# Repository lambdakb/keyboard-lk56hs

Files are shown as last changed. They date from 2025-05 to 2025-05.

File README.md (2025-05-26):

# LK56HS 55% Staggered Hot-Swappable Keyboard






## Layout

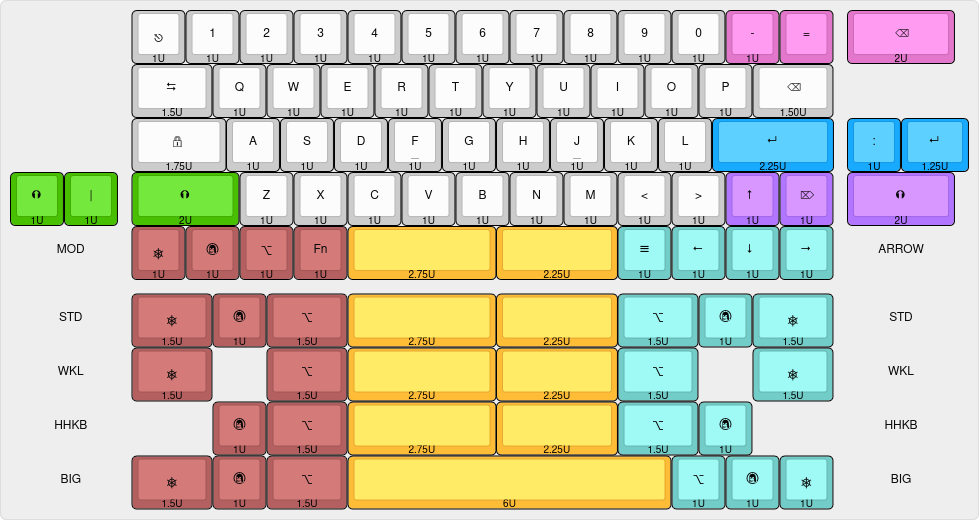
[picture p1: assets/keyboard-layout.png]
Layout


[Keyboard Layout Editor](https://www.keyboard-layout-editor.com/##@_css=%3B&@_x:2.25&p=R1&a:7%3B&=%3Ci%20class%2F='mss%20mss-Unicode-Escape-3'%3E%3C%2F%2Fi%3E%0A%0A%0A%0A1U&=1%0A%0A%0A%0A1U&=2%0A%0A%0A%0A1U&=3%0A%0A%0A%0A1U&=4%0A%0A%0A%0A1U&=5%0A%0A%0A%0A1U&=6%0A%0A%0A%0A1U&=7%0A%0A%0A%0A1U&=8%0A%0A%0A%0A1U&=9%0A%0A%0A%0A1U&=0%0A%0A%0A%0A1U&_c=%23e377cc%3B&=-%0A%0A%0A%0A1U&=%2F=&_x:0.25&p=R4&w:2%3B&=%3Ci%20class%2F='kb%20kb-Unicode-BackSpace-DeleteLeft-Big'%3E%3C%2F%2Fi%3E%0A%0A%0A%0A2U%3B&@_x:2.25&c=%23cccccc&p=R2&w:1.5%3B&=%3Ci%20class%2F='kb%20kb-Tab-1'%3E%3C%2F%2Fi%3E%0A%0A%0A%0A1.5U&=Q%0A%0A%0A%0A1U&=W%0A%0A%0A%0A1U&=E%0A%0A%0A%0A1U&=R%0A%0A%0A%0A1U&=T%0A%0A%0A%0A1U&=Y%0A%0A%0A%0A1U&=U%0A%0A%0A%0A1U&=I%0A%0A%0A%0A1U&=O%0A%0A%0A%0A1U&=P%0A%0A%0A%0A1U&_w:1.5%3B&=%3Ci%20class%2F='kb%20kb-Unicode-BackSpace-DeleteLeft-Big'%3E%3C%2F%2Fi%3E%0A%0A%0A%0A1.50U%3B&@_x:2.25&p=R3&w:1.75%3B&=%3Ci%20class%2F='kb%20kb-Unicode-Lock-Closed-1'%3E%3C%2F%2Fi%3E%0A%0A%0A%0A1.75U&=A%0A%0A%0A%0A1U&=S%0A%0A%0A%0A1U&=D%0A%0A%0A%0A1U&_n:true%3B&=F%0A%0A%0A%0A1U&=G%0A%0A%0A%0A1U&=H%0A%0A%0A%0A1U&_n:true%3B&=J%0A%0A%0A%0A1U&=K%0A%0A%0A%0A1U&=L%0A%0A%0A%0A1U&_c=%2317aaff&p=R4&w:2.25%3B&=%3Ci%20class%2F='kb%20kb-Return-2'%3E%3C%2F%2Fi%3E%0A%0A%0A%0A2.25U&_x:0.25%3B&=%2F:%0A%0A%0A%0A1U&_w:1.25%3B&=%3Ci%20class%2F='kb%20kb-Return-2'%3E%3C%2F%2Fi%3E%0A%0A%0A%0A1.25U%3B&@_c=%2348bf00%3B&=%3Ci%20class%2F='kb%20kb-Arrows-Up-Circle-Filled'%3E%3C%2F%2Fi%3E%0A%0A%0A%0A1U&=%7C%0A%0A%0A%0A1U&_x:0.25&w:2%3B&=%3Ci%20class%2F='kb%20kb-Arrows-Up-Circle-Filled'%3E%3C%2F%2Fi%3E%0A%0A%0A%0A2U&_c=%23cccccc%3B&=Z%0A%0A%0A%0A1U&=X%0A%0A%0A%0A1U&=C%0A%0A%0A%0A1U&=V%0A%0A%0A%0A1U&=B%0A%0A%0A%0A1U&=N%0A%0A%0A%0A1U&=M%0A%0A%0A%0A1U&=%3C%0A%0A%0A%0A1U&=%3E%0A%0A%0A%0A1U&_c=%23b275ff%3B&=%3Ci%20class%2F='kb%20kb-Arrows-Up'%3E%3C%2F%2Fi%3E%0A%0A%0A%0A1U&=%3Ci%20class%2F='kb%20kb-Unicode-DeleteRight-Big'%3E%3C%2F%2Fi%3E%0A%0A%0A%0A1U&_x:0.25&w:2%3B&=%3Ci%20class%2F='kb%20kb-Arrows-Up-Circle-Filled'%3E%3C%2F%2Fi%3E%0A%0A%0A%0A2U%3B&@_c=%23cccccc&p=R2&w:2.25&d:true%3B&=MOD&_c=%23b56060&p=R4%3B&=%3Ci%20class%2F='mss%20mss-Unicode-Control-4'%3E%3C%2F%2Fi%3E%0A%0A%0A%0A1U&=%3Ci%20class%2F='kb%20kb-logo-linux-tux-ibm'%3E%3C%2F%2Fi%3E%0A%0A%0A%0A1U&=%3Ci%20class%2F='mss%20mss-Unicode-Option-3'%3E%3C%2F%2Fi%3E%0A%0A%0A%0A1U&=Fn%0A%0A%0A%0A1U&_c=%23ffbc36&p=SPACE&w:2.75%3B&=%0A%0A%0A%0A2.75U&_w:2.25%3B&=%0A%0A%0A%0A2.25U&_c=%2372ccc7%3B&=%3Ci%20class%2F='kb%20kb-Hamburger-Menu'%3E%3C%2F%2Fi%3E%0A%0A%0A%0A1U&_p=R2%3B&=%3Ci%20class%2F='kb%20kb-Arrows-Left'%3E%3C%2F%2Fi%3E%0A%0A%0A%0A1U&=%3Ci%20class%2F='kb%20kb-Arrows-Down'%3E%3C%2F%2Fi%3E%0A%0A%0A%0A1U&=%3Ci%20class%2F='kb%20kb-Arrows-Right'%3E%3C%2F%2Fi%3E%0A%0A%0A%0A1U&_c=%23cccccc&w:2.5&d:true%3B&=ARROW%3B&@_y:0.25&w:2.25&d:true%3B&=STD&_c=%23b56060&p=R4&w:1.5%3B&=%3Ci%20class%2F='mss%20mss-Unicode-Control-4'%3E%3C%2F%2Fi%3E%0A%0A%0A%0A1.5U&=%3Ci%20class%2F='kb%20kb-logo-linux-tux-ibm'%3E%3C%2F%2Fi%3E%0A%0A%0A%0A1U&_w:1.5%3B&=%3Ci%20class%2F='mss%20mss-Unicode-Option-3'%3E%3C%2F%2Fi%3E%0A%0A%0A%0A1.5U&_c=%23ffbc36&p=SPACE&w:2.75%3B&=%0A%0A%0A%0A2.75U&_w:2.25%3B&=%0A%0A%0A%0A2.25U&_c=%2372ccc7&p=R2&w:1.5%3B&=%3Ci%20class%2F='mss%20mss-Unicode-Option-3'%3E%3C%2F%2Fi%3E%0A%0A%0A%0A1.5U&_p=R4%3B&=%3Ci%20class%2F='kb%20kb-logo-linux-tux-ibm'%3E%3C%2F%2Fi%3E%0A%0A%0A%0A1U&_p=R2&w:1.5%3B&=%3Ci%20class%2F='mss%20mss-Unicode-Control-4'%3E%3C%2F%2Fi%3E%0A%0A%0A%0A1.5U&_c=%23cccccc&w:2.5&d:true%3B&=STD%3B&@_w:2.25&d:true%3B&=WKL&_c=%23b56060&p=R4&w:1.5%3B&=%3Ci%20class%2F='mss%20mss-Unicode-Control-4'%3E%3C%2F%2Fi%3E%0A%0A%0A%0A1.5U&_x:1&w:1.5%3B&=%3Ci%20class%2F='mss%20mss-Unicode-Option-3'%3E%3C%2F%2Fi%3E%0A%0A%0A%0A1.5U&_c=%23ffbc36&p=SPACE&w:2.75%3B&=%0A%0A%0A%0A2.75U&_w:2.25%3B&=%0A%0A%0A%0A2.25U&_c=%2372ccc7&p=R2&w:1.5%3B&=%3Ci%20class%2F='mss%20mss-Unicode-Option-3'%3E%3C%2F%2Fi%3E%0A%0A%0A%0A1.5U&_x:1&w:1.5%3B&=%3Ci%20class%2F='mss%20mss-Unicode-Control-4'%3E%3C%2F%2Fi%3E%0A%0A%0A%0A1.5U&_c=%23cccccc&w:2.5&d:true%3B&=WKL%3B&@_w:2.25&d:true%3B&=HHKB&_x:1.5&c=%23b56060&p=R4%3B&=%3Ci%20class%2F='kb%20kb-logo-linux-tux-ibm'%3E%3C%2F%2Fi%3E%0A%0A%0A%0A1U&_w:1.5%3B&=%3Ci%20class%2F='mss%20mss-Unicode-Option-3'%3E%3C%2F%2Fi%3E%0A%0A%0A%0A1.5U&_c=%23ffbc36&p=SPACE&w:2.75%3B&=%0A%0A%0A%0A2.75U&_w:2.25%3B&=%0A%0A%0A%0A2.25U&_c=%2372ccc7&p=R2&w:1.5%3B&=%3Ci%20class%2F='mss%20mss-Unicode-Option-3'%3E%3C%2F%2Fi%3E%0A%0A%0A%0A1.5U&_p=R4%3B&=%3Ci%20class%2F='kb%20kb-logo-linux-tux-ibm'%3E%3C%2F%2Fi%3E%0A%0A%0A%0A1U&_x:1.5&c=%23cccccc&p=R2&w:2.5&d:true%3B&=HHKB%3B&@_w:2.25&d:true%3B&=BIG&_c=%23b56060&p=R4&w:1.5%3B&=%3Ci%20class%2F='mss%20mss-Unicode-Control-4'%3E%3C%2F%2Fi%3E%0A%0A%0A%0A1.5U&=%3Ci%20class%2F='kb%20kb-logo-linux-tux-ibm'%3E%3C%2F%2Fi%3E%0A%0A%0A%0A1U&_w:1.5%3B&=%3Ci%20class%2F='mss%20mss-Unicode-Option-3'%3E%3C%2F%2Fi%3E%0A%0A%0A%0A1.5U&_c=%23ffbc36&p=SPACE&w:6%3B&=%0A%0A%0A%0A6U&_c=%2372ccc7&p=R2%3B&=%3Ci%20class%2F='mss%20mss-Unicode-Option-3'%3E%3C%2F%2Fi%3E%0A%0A%0A%0A1U&=%3Ci%20class%2F='kb%20kb-logo-linux-tux-ibm'%3E%3C%2F%2Fi%3E%0A%0A%0A%0A1U&=%3Ci%20class%2F='mss%20mss-Unicode-Control-4'%3E%3C%2F%2Fi%3E%0A%0A%0A%0A1U&_c=%23cccccc&w:2.5&d:true%3B&=BIG)

## PCB

| PCB (Front) | PCB (Back) |
| :---: | :---: |
| [PCB Front][PCB Front PNG] | [PCB Back][PCB Back PNG] |

[PCB Front]: output/pcb/img/lk56hs-pcb-top.svg
[PCB Front PNG]: output/pcb/img/lk56hs-pcb-top.png
[PCB Back]: output/pcb/img/lk56hs-pcb-bottom.svg
[PCB Back PNG]: output/pcb/img/lk56hs-pcb-bottom.png

The PCB has been designed in [KiCad EDA 9.0](https://www.kicad.org/) using the [`kicad-lkbd`](https://github.com/lambdakb/kicad-lkbd) libraries and [`kbplacer`](https://github.com/adamws/kicad-kbplacer).

You can preview the project files using [KiCanvas](https://kicanvas.org/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) directly in your browser and download the latest fabrication files for JLCPCB from the [latest release](https://github.com/lambdakb/keyboard-lk56hs/releases/latest/).

The exported schematic is also available under [`output/schematics`](output/schematics/).

### PCB Order

| Parameters | Value |
| --- | --- |
| Base Material | FR4 |
| Layers | 2 |
| Dimensions | 247.65 × 95.25 mm |
| PCB Thickness | 1.6 mm |
| PCB Color | Blue |
| Silkscreen | White |
| Surface Finish [^surface-finish] | Lead Free HASL or ENIG |
| Copper Weight | 1 oz |
| Via Covering | Tented |
| Min Via Hole Size | 0.3 mm |
| Board Outline Tolerance | ± 0.2 mm |

[^surface-finish]: The "HASL (with lead)" option is extremely discouraged due to the risk of lead poisoning. We strongly recommend paying the premium for the "Lead Free HASL" option.

## Cases

### FR4

| Plate (Top) | Plate (Bottom) |
| :---: | :---: |
| [Plate Top][Plate Top PNG] | [Plate Bottom][Plate Bottom PNG] |

[Plate Top]: output/plate/img/lk56hs-plate-top.svg
[Plate Top PNG]: output/plate/img/lk56hs-plate-top.png
[Plate Bottom]: output/plate/img/lk56hs-plate-bottom.svg
[Plate Bottom PNG]: output/plate/img/lk56hs-plate-bottom.png

The plate has also been designed in [KiCad EDA 9.0](https://www.kicad.org/) using the [`kicad-lkbd`](https://github.com/lambdakb/kicad-lkbd) libraries.

It is reversible, so you can choose to either have a wave pattern design shown or just a plain PCB plate. It can be used alongside another Keyboard PCB to create a full case by stacking:

- Plate PCB (any direction)
- Assemble Keyboard PCB
- Reversed Unpopulated Keyboard PCB

Use the same parameters present in [PCB Order](./README.md#pcb-order) to order the plate and bottom PCB, you can find the fabrication files in [`output/plate/fabrication/jlcpcb`](output/plate/fabrication/jlcpcb/).

Be careful, JLCPCB may charge an extra fee for this PCB because it has "too many holes". You may want to prefer 3D printing a full case instead.

If you prefer to fabricate it by any other mean (such as laser cut acrylic), you can download their board outlines as `DXF` in [`output/plate/dxf`](output/plate/dxf).

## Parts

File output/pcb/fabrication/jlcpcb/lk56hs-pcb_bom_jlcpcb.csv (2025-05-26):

Comment | Designator | Footprint Type | Footprint | LCSC | JLC | QTY
100nF | C1,C2 | SMD | Capacitor_SMD_1206_inSilk | C24497 | 1206 | 2
D | D1,D2,D3,D4,D5,D6,D7,D8,D9,D10,D11,D12,D14,D15,D16,D17,D18,D19,D20,D21,D22,D23,D24,D25,D26,D27,D28,D29,D30,D31,D32,D33,D34,D35,D36,D37,D38,D40,D42,D43,D44,D45,D46,D47,D48,D49,D50,D51,D52,D53,D55,D57,D59,D60,D62,D64,D65,D67,D69,D70 | SMD | Diode_SMD_SOD-123_inSilk | C81598 | SOD-123 | 60
RotaryEncoder_Switch_MP | SW1 | SMD | SW_MX_EC11_HotSwap_nSilk | C41430893 | SMD,14.5x5.9mm | 1
SW_Push | SW2,SW3,SW4,SW5,SW6,SW7,SW8,SW9,SW10,SW11,SW12,SW13,SW14,SW15,SW16,SW17,SW18,SW19,SW20,SW21,SW22,SW23,SW24,SW25,SW26,SW27,SW28,SW29,SW30,SW31,SW32,SW33,SW34,SW35,SW36,SW37,SW38,SW39,SW40,SW41,SW42,SW43,SW44,SW45,SW46,SW47,SW48,SW49,SW50,SW51,SW52,SW53,SW54,SW55,SW56,SW57,SW58,SW59,SW60,SW61,SW62,SW63,SW64,SW65,SW66,SW67,SW68,SW69,SW70,SW71 | SMD | SW_MX_HotSwap_nSilk | C41430893 | SMD,14.5x5.9mm | 70

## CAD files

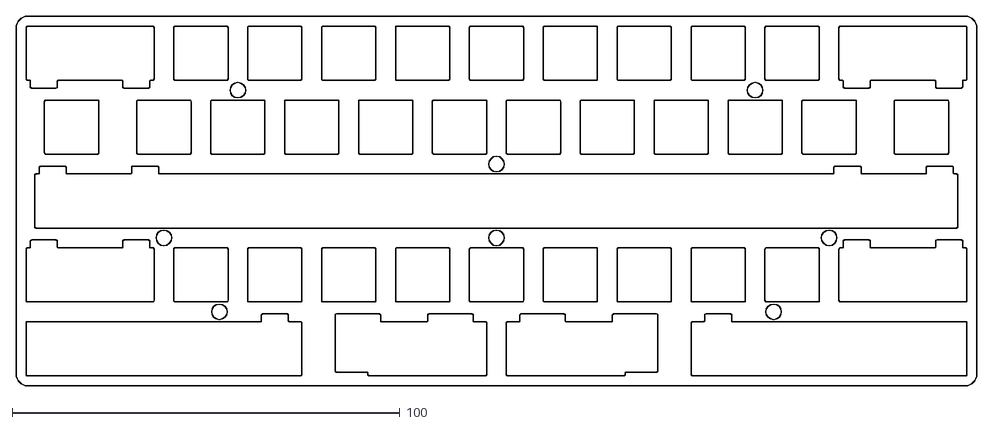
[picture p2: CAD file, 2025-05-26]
output/plate/dxf/lk56hs-plate.dxf
247.7 x 95.2

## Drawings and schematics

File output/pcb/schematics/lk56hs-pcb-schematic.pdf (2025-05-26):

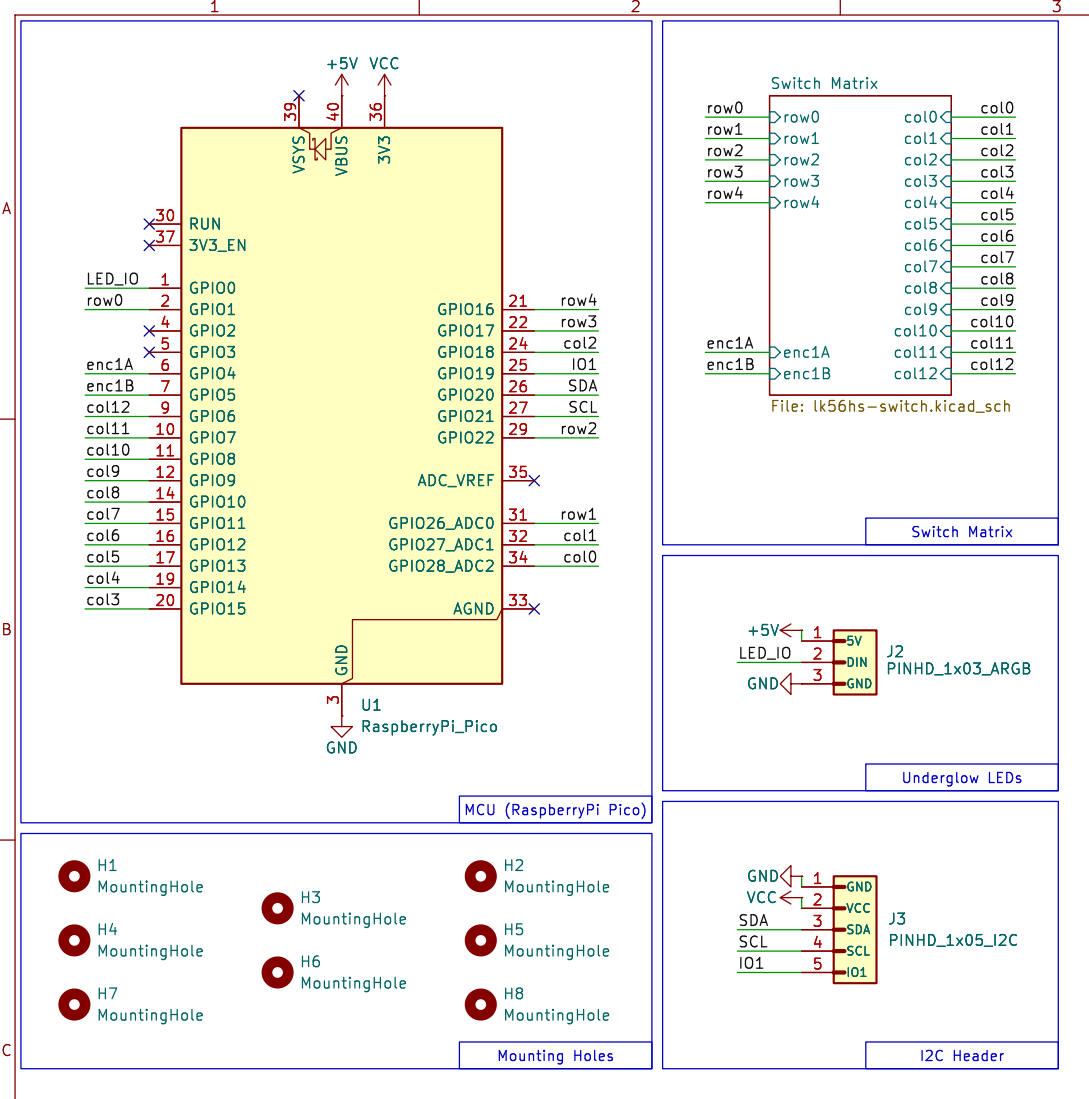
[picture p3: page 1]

https://lambdakb.dev/devices/lk56hs/
File: lk56hs-pcb.kicad_sch Sheet: / LambdaKB.dev

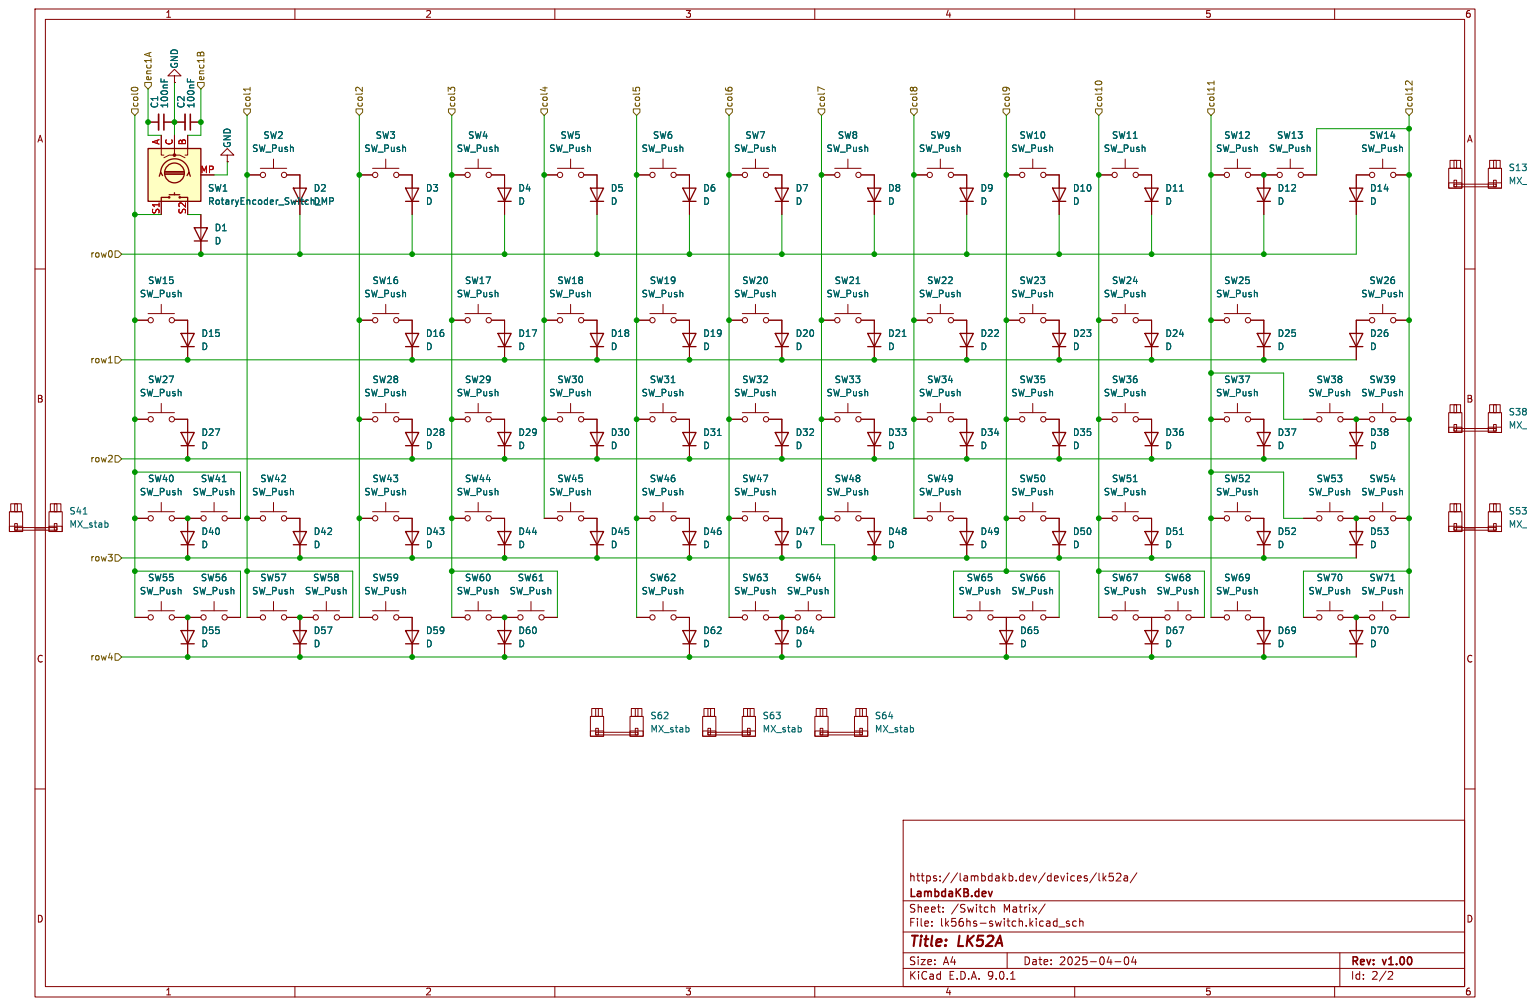
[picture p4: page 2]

https://lambdakb.dev/devices/lk52a/

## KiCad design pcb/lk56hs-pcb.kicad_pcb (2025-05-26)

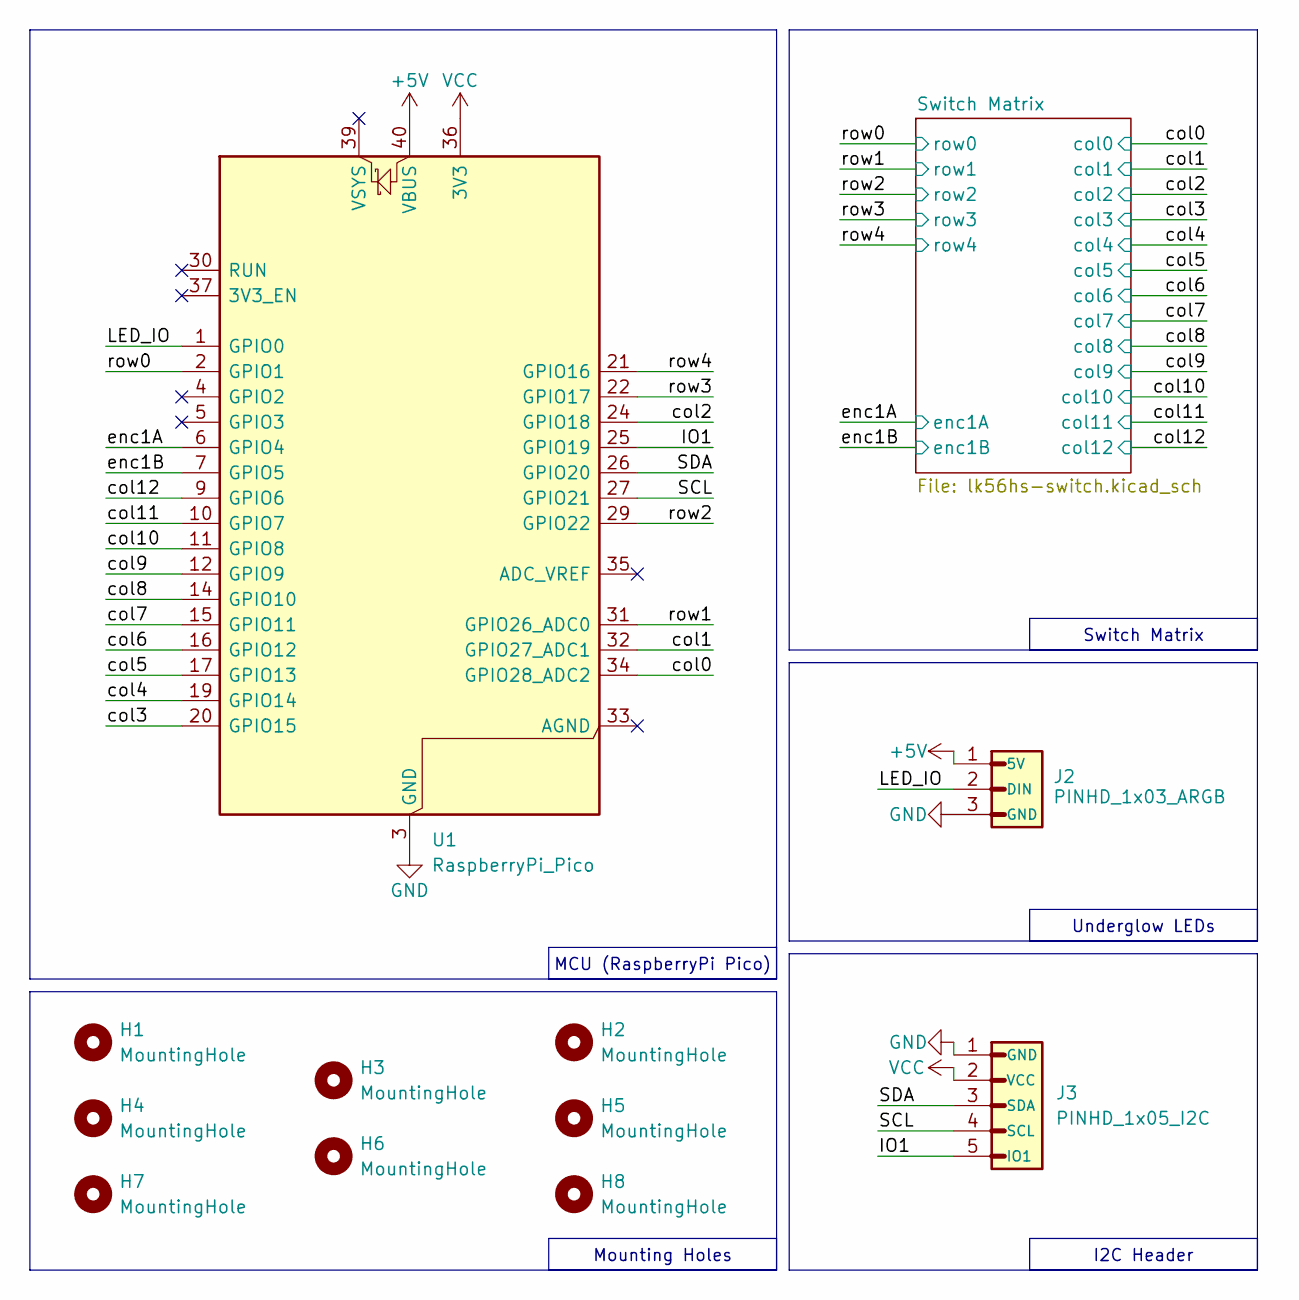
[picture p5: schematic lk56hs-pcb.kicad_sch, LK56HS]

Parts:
H1, H2, H3, H4, H5, H6, H7, H8: MountingHole; MountingHole_M2_NoPad
J2: PINHD_1x03_ARGB; PinHeader_1x03_THT_P2.54mm_nSilk
J3: PINHD_1x05_I2C; PinHeader_1x05_THT_P2.54mm_nSilk
U1: RaspberryPi_Pico; MCU_RaspberryPi_Pico_THT

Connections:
+5V: J2.1 (5V), U1.40 (VBUS)
/IO1: J3.5 (IO1), U1.25 (GPIO19)
/LED_IO: J2.2 (DIN), U1.1 (GPIO0)
/SCL: J3.4 (SCL), U1.27 (GPIO21)
/SDA: J3.3 (SDA), U1.26 (GPIO20)
/col0: U1.34 (GPIO28_ADC2); also elsewhere on the board
/col1: U1.32 (GPIO27_ADC1); also elsewhere on the board
/col2: U1.24 (GPIO18); also elsewhere on the board
/col3: U1.20 (GPIO15); also elsewhere on the board
/col4: U1.19 (GPIO14); also elsewhere on the board
/col5: U1.17 (GPIO13); also elsewhere on the board
/col6: U1.16 (GPIO12); also elsewhere on the board
/col7: U1.15 (GPIO11); also elsewhere on the board
/col8: U1.14 (GPIO10); also elsewhere on the board
/col9: U1.12 (GPIO9); also elsewhere on the board
/col10: U1.11 (GPIO8); also elsewhere on the board
/col11: U1.10 (GPIO7); also elsewhere on the board
/col12: U1.9 (GPIO6); also elsewhere on the board
/enc1A: U1.6 (GPIO4); also elsewhere on the board
/enc1B: U1.7 (GPIO5); also elsewhere on the board
/row0: U1.2 (GPIO1); also elsewhere on the board
/row1: U1.31 (GPIO26_ADC0); also elsewhere on the board
/row2: U1.29 (GPIO22); also elsewhere on the board
/row3: U1.22 (GPIO17); also elsewhere on the board
/row4: U1.21 (GPIO16); also elsewhere on the board
GND: J2.3 (GND), J3.1 (GND), U1.3 (GND), U1.8 (GND), U1.13 (GND), U1.18 (GND), U1.23 (GND), U1.28 (GND), U1.38 (GND); also elsewhere on the board
VCC: J3.2 (VCC), U1.36 (3V3)

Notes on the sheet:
Mounting Holes
Switch Matrix
MCU (RaspberryPi Pico)
Underglow LEDs
I2C Header

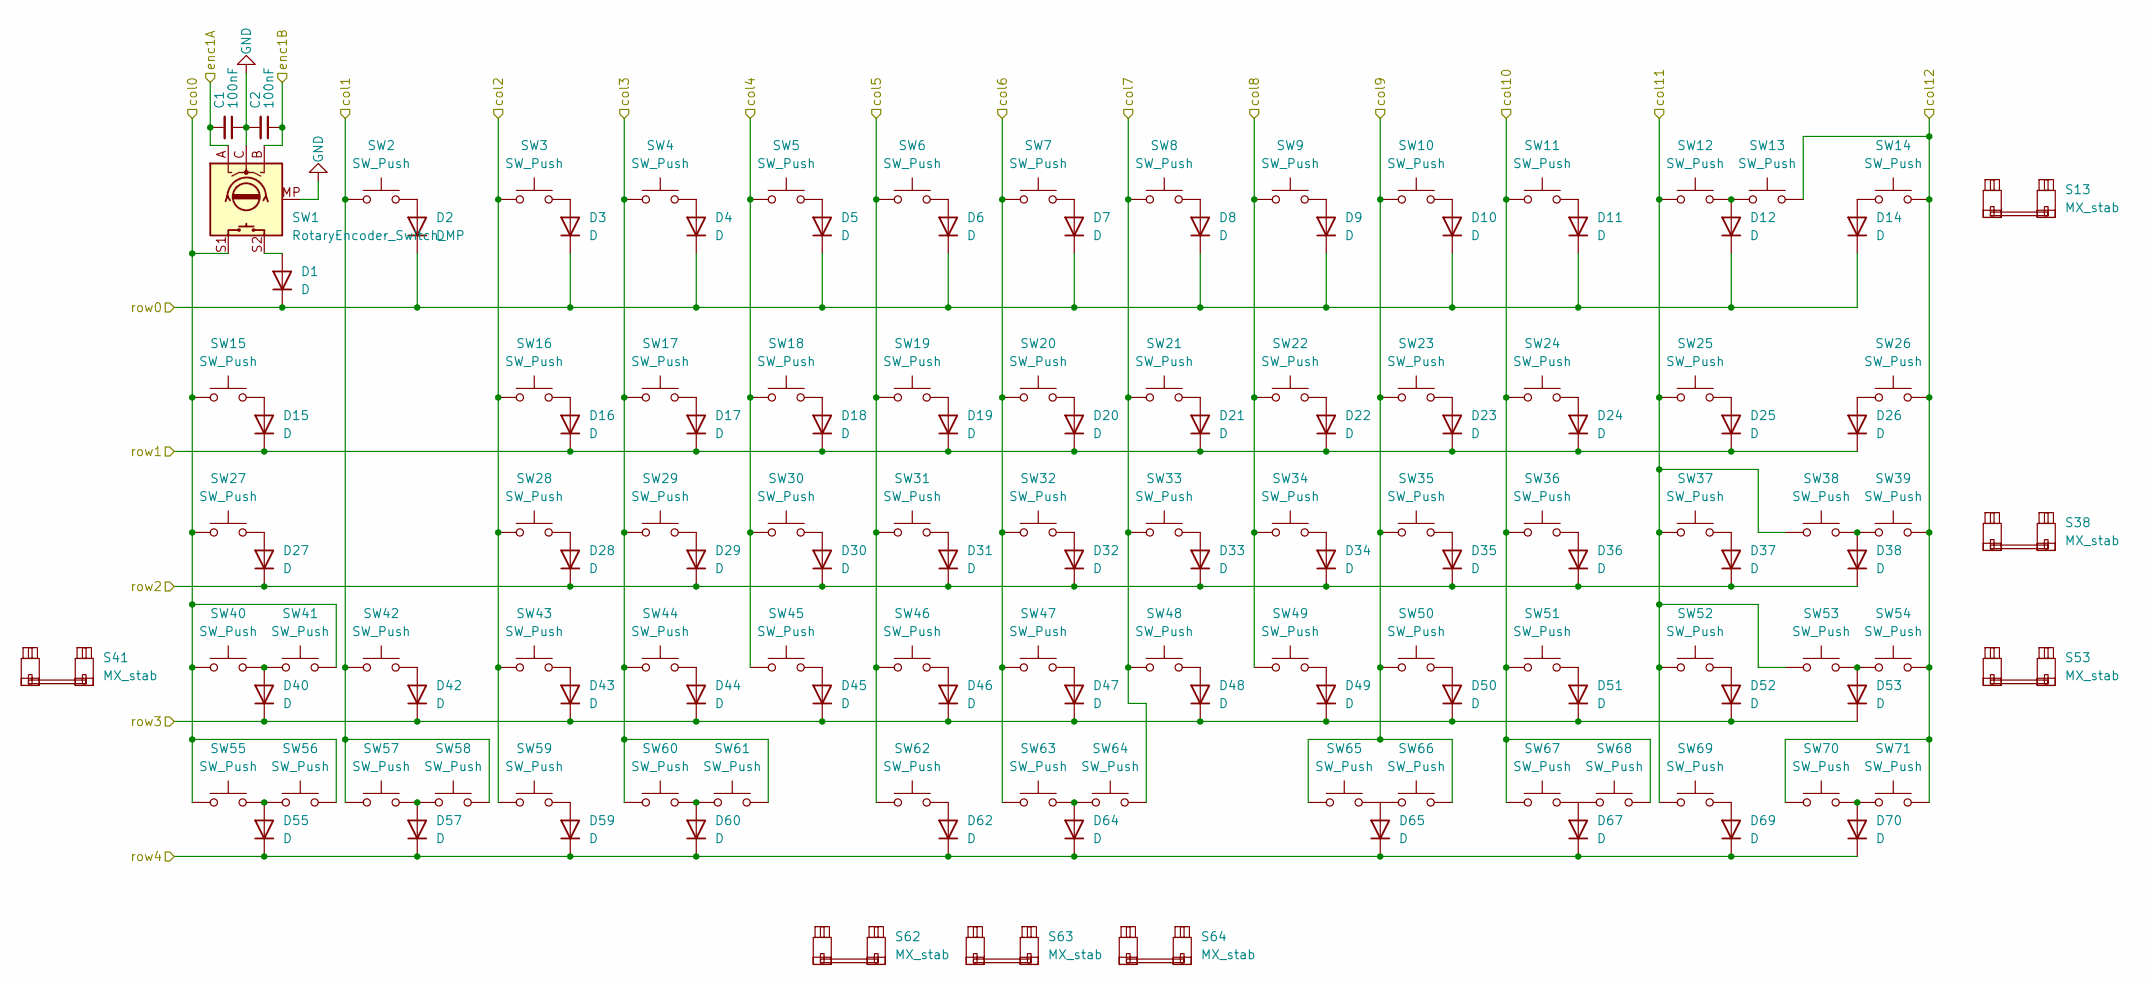
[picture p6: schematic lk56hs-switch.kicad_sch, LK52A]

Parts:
C1, C2: 100nF; Capacitor_SMD_1206_inSilk; LCSC C24497
D1, D2, D3, D4, D5, D6, D7, D8, D9, D10, D11, D12, D14, D15, D16, D17, D18, D19, D20, D21, D22, D23, D24, D25, D26, D27, D28, D29, D30, D31, D32, D33, D34, D35, D36, D37, D38, D40, D42, D43, D44, D45, D46, D47, D48, D49, D50, D51, D52, D53, D55, D57, D59, D60, D62, D64, D65, D67, D69, D70: D; Diode_SMD_SOD-123_inSilk; JLC SOD-123
S13, S38, S41, S53, S62, S64: MX_stab; Stabilizer_MX_2U
S63: MX_stab; Stabilizer_MX_6U
SW1: RotaryEncoder_Switch_MP; SW_MX_EC11_HotSwap_nSilk; JLC SMD,14.5x5.9mm
SW2, SW3, SW4, SW5, SW6, SW7, SW8, SW9, SW10, SW11, SW12, SW13, SW14, SW15, SW16, SW17, SW18, SW19, SW20, SW21, SW22, SW23, SW24, SW25, SW26, SW27, SW28, SW29, SW30, SW31, SW32, SW33, SW34, SW35, SW36, SW37, SW38, SW39, SW40, SW41, SW42, SW43, SW44, SW45, SW46, SW47, SW48, SW49, SW50, SW51, SW52, SW53, SW54, SW55, SW56, SW57, SW58, SW59, SW60, SW61, SW62, SW63, SW64, SW65, SW66, SW67, SW68, SW69, SW70, SW71: SW_Push; SW_MX_HotSwap_nSilk; JLC SMD,14.5x5.9mm

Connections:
/col0: SW1.S1, SW15.1, SW27.1, SW40.1, SW41.1, SW55.2, SW56.1; also elsewhere on the board
/col1: SW2.1, SW42.1, SW57.2, SW58.2; also elsewhere on the board
/col2: SW3.1, SW16.1, SW28.1, SW43.1, SW59.2; also elsewhere on the board
/col3: SW4.1, SW17.1, SW29.1, SW44.1, SW60.2, SW61.1; also elsewhere on the board
/col4: SW5.1, SW18.1, SW30.1, SW45.1; also elsewhere on the board
/col5: SW6.1, SW19.1, SW31.1, SW46.1, SW62.1; also elsewhere on the board
/col6: SW7.1, SW20.1, SW32.1, SW47.1, SW63.1; also elsewhere on the board
/col7: SW8.1, SW21.1, SW33.1, SW48.1, SW64.1; also elsewhere on the board
/col8: SW9.1, SW22.1, SW34.1, SW49.1; also elsewhere on the board
/col9: SW10.1, SW23.1, SW35.1, SW50.1, SW65.2, SW66.1; also elsewhere on the board
/col10: SW11.1, SW24.1, SW36.1, SW51.1, SW67.1, SW68.1; also elsewhere on the board
/col11: SW12.2, SW25.2, SW37.2, SW38.2, SW52.2, SW53.2, SW69.1; also elsewhere on the board
/col12: SW13.2, SW14.2, SW26.1, SW39.1, SW54.1, SW70.2, SW71.1; also elsewhere on the board
/enc1A: C1.2, SW1.A; also elsewhere on the board
/enc1B: C2.1, SW1.B; also elsewhere on the board
/row0: D1.1 (K), D2.1 (K), D3.1 (K), D4.1 (K), D5.1 (K), D6.1 (K), D7.1 (K), D8.1 (K), D9.1 (K), D10.1 (K), D11.1 (K), D12.1 (K), D14.1 (K); also elsewhere on the board
/row1: D15.1 (K), D16.1 (K), D17.1 (K), D18.1 (K), D19.1 (K), D20.1 (K), D21.1 (K), D22.1 (K), D23.1 (K), D24.1 (K), D25.1 (K), D26.1 (K); also elsewhere on the board
/row2: D27.1 (K), D28.1 (K), D29.1 (K), D30.1 (K), D31.1 (K), D32.1 (K), D33.1 (K), D34.1 (K), D35.1 (K), D36.1 (K), D37.1 (K), D38.1 (K); also elsewhere on the board
/row3: D40.1 (K), D42.1 (K), D43.1 (K), D44.1 (K), D45.1 (K), D46.1 (K), D47.1 (K), D48.1 (K), D49.1 (K), D50.1 (K), D51.1 (K), D52.1 (K), D53.1 (K); also elsewhere on the board
/row4: D55.1 (K), D57.1 (K), D59.1 (K), D60.1 (K), D62.1 (K), D64.1 (K), D65.1 (K), D67.1 (K), D69.1 (K), D70.1 (K); also elsewhere on the board
GND: C1.1, C2.2, SW1.C, SW1.MP; also elsewhere on the board
unnamed: D1.2 (A), SW1.S2
unnamed: D2.2 (A), SW2.2
unnamed: D3.2 (A), SW3.2
unnamed: D4.2 (A), SW4.2
unnamed: D5.2 (A), SW5.2
unnamed: D6.2 (A), SW6.2
unnamed: D7.2 (A), SW7.2
unnamed: D8.2 (A), SW8.2
unnamed: D9.2 (A), SW9.2
unnamed: D10.2 (A), SW10.2
unnamed: D11.2 (A), SW11.2
unnamed: D12.2 (A), SW12.1, SW13.1
unnamed: D14.2 (A), SW14.1
unnamed: D15.2 (A), SW15.2
unnamed: D16.2 (A), SW16.2
unnamed: D17.2 (A), SW17.2
unnamed: D18.2 (A), SW18.2
unnamed: D19.2 (A), SW19.2
unnamed: D20.2 (A), SW20.2
unnamed: D21.2 (A), SW21.2
unnamed: D22.2 (A), SW22.2
unnamed: D23.2 (A), SW23.2
unnamed: D24.2 (A), SW24.2
unnamed: D25.2 (A), SW25.1
unnamed: D26.2 (A), SW26.2
unnamed: D27.2 (A), SW27.2
unnamed: D28.2 (A), SW28.2
unnamed: D29.2 (A), SW29.2
unnamed: D30.2 (A), SW30.2
unnamed: D31.2 (A), SW31.2
unnamed: D32.2 (A), SW32.2
unnamed: D33.2 (A), SW33.2
unnamed: D34.2 (A), SW34.2
unnamed: D35.2 (A), SW35.2
unnamed: D36.2 (A), SW36.2
unnamed: D37.2 (A), SW37.1
unnamed: D38.2 (A), SW38.1, SW39.2
unnamed: D40.2 (A), SW40.2, SW41.2
unnamed: D42.2 (A), SW42.2
unnamed: D43.2 (A), SW43.2
unnamed: D44.2 (A), SW44.2
unnamed: D45.2 (A), SW45.2
unnamed: D46.2 (A), SW46.2
unnamed: D47.2 (A), SW47.2
unnamed: D48.2 (A), SW48.2
unnamed: D49.2 (A), SW49.2
unnamed: D50.2 (A), SW50.2
unnamed: D51.2 (A), SW51.2
unnamed: D52.2 (A), SW52.1
unnamed: D53.2 (A), SW53.1, SW54.2
unnamed: D55.2 (A), SW55.1, SW56.2
unnamed: D57.2 (A), SW57.1, SW58.1
unnamed: D59.2 (A), SW59.1
unnamed: D60.2 (A), SW60.1, SW61.2
unnamed: D62.2 (A), SW62.2
unnamed: D64.2 (A), SW63.2, SW64.2
unnamed: D65.2 (A), SW65.1, SW66.2
unnamed: D67.2 (A), SW67.2, SW68.2
unnamed: D69.2 (A), SW69.2
unnamed: D70.2 (A), SW70.1, SW71.2

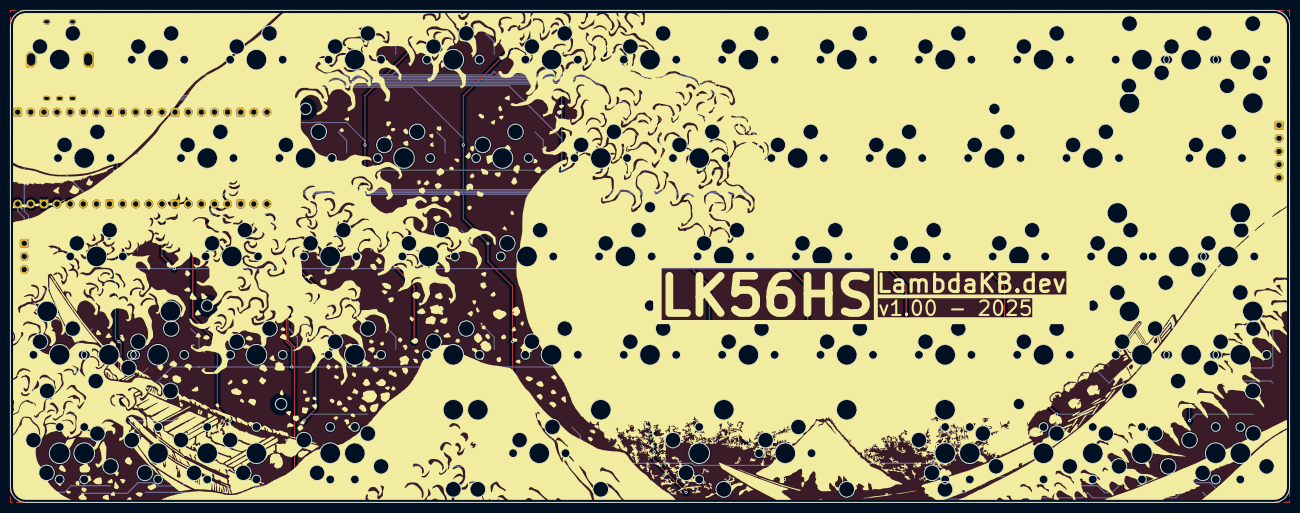
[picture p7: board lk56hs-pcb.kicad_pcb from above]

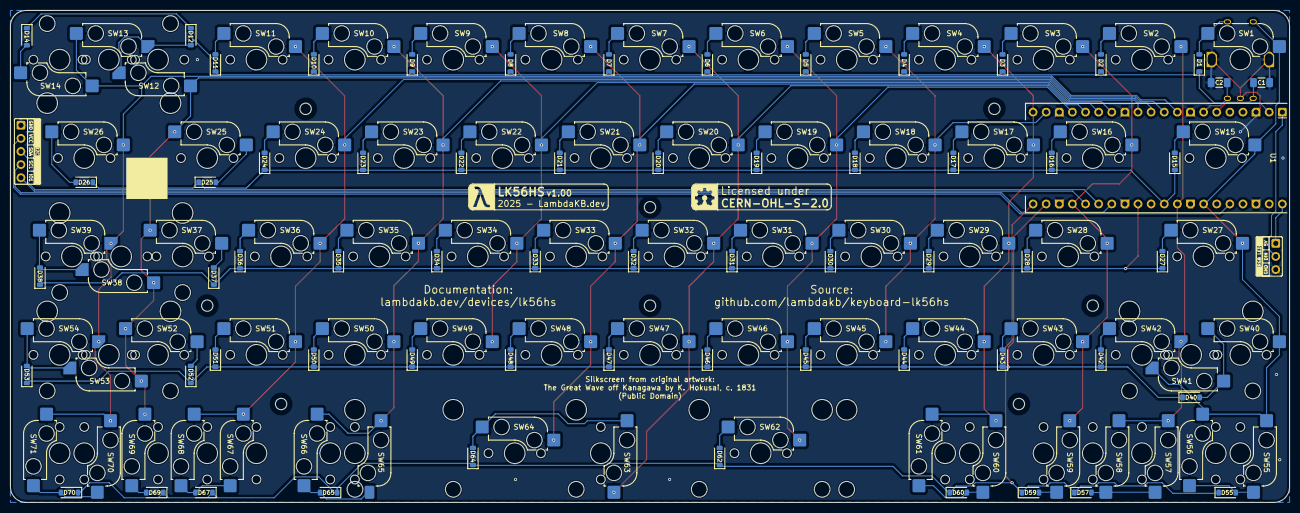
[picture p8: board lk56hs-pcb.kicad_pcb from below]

Board: 2 copper layers, 247.7 x 95.2 mm, 152 parts (137 on the bottom side), 87 nets.

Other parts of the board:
FAB1: JLCPCB_2DBarcode_8x8mm

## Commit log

2025-05-20 Add LK56HS PCB prototype
    [lk56hs-pcb.kicad_sch, lk56hs-switch.kicad_sch]
2025-05-20 Add output
    [lk56hs-pcb_bom_jlcpcb.csv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]
2025-05-20 Update silkscreen
2025-05-20 Add simple plate
    [lk56hs-pcb.kicad_sch, lk56hs-plate-3D.step, lk56hs-plate.dxf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]
2025-05-20 Update stabilizers
    [lk56hs-plate-3D.step, lk56hs-plate.dxf, lk56hs-plate.kicad_pcb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]
2025-05-26 Make plate reversible and add graphics
    [lk56hs-pcb.kicad_pcb, lk56hs-pcb.kicad_sch, lk56hs-pcb_bom_jlcpcb.csv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]
2025-05-26 Fix CPL output
    [lk56hs-pcb.kicad_pcb, lk56hs-switch.kicad_sch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]
2025-05-26 Update plate color and add case to README.md

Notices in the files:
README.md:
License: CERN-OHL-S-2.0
